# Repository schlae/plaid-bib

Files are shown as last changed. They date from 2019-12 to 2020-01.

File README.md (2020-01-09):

# The Plaid Bib - an Ad Lib MCA Clone

**This card uses the P82C611 bus interface chip and will not work with faster
MCA systems. For a more widely-compatible version, use the [Plaid Bib CPLD
version](https://github.com/schlae/plaid-bib-cpld).**

The Plaid Bib is a 100% compatible clone of the Ad Lib MCA sound card. This is
an Ad Lib card designed for Micro Channel Architecture machines, such as the
IBM PS/2 family and other compatibles from NCR, Tandy, Dell, and others.

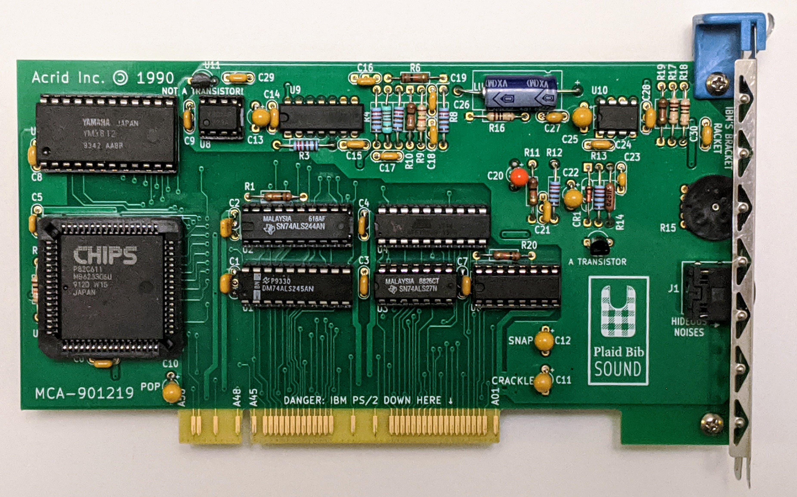
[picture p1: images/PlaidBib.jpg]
Plaid Bib photo


Here are the design files. The BOM includes Mouser Electronics part numbers for
everything except for the 82C611, YM3812, and YM3014B, all of which are
available from brokers in China such as UTSource.

[Schematic](https://github.com/schlae/plaid-bib/blob/master/PlaidBib.pdf)

[Bill of Materials](https://github.com/schlae/plaid-bib/blob/master/PlaidBib.csv)

[Fab Files](https://github.com/schlae/plaid-bib/blob/master/fab/PlaidBib-fab.zip)

Use caution when obtaining the P82C611 MCA bus interface part. There is another
chip with the same part number from OPTi, except it is a VLB IDE controller and
totally different.

## Fabrication Notes
This is a two-layer board, outer dimensions 6.452in x 3.475in (164mm x 88mm).
Thickness of the board is 0.063in (1.6mm). When ordering the board, specify
a card edge bevel of 20 degrees. The Dwgs.User layer includes a detail with
the dimensions of the bevel.

Ideally you should use selective gold plating for the edge fingers, but this
can get expensive for small orders. ENIG will work but the gold will rub off
pretty quickly.

For the soldermask color, pick whatever you want! The original was green.

## Assembly Notes
You may wish to socket U7, U8, and U4. These sockets are not included in the
BOM. U7 and U8 are the Yamaha synthesizer chips, and it is useful to be able
to swap them out in case you get a bad one. U4 is the PAL; consider using a
socket in case of programming difficulties.

## PAL Notes
There is a programmable logic device that implements the address decoder and an
address bit latch. The original card uses a 16L8, but the Plaid Bib uses a
readily-available Atmel ATF16V8B. Here is the
[WinCUPL source](https://github.com/schlae/plaid-bib/blob/master/pld/plaidbib.pld)
and the resulting 
[JEDEC file](https://github.com/schlae/plaid-bib/blob/master/pld/plaidbib.jed).
You will need a device programmer such as the low-cost TL866A/CS. 

## Bracket
MCA brackets are no longer available. You have a few options:
- Remove the bracket from an existing card, like a token ring card or something
- 3D print the bracket
- Use the card without a bracket at all

If you want to print your own, here are STEP models of the bracket and the
plastic clip.

[Bracket](https://github.com/schlae/plaid-bib/blob/master/mech/MCABracket.STEP)

[Clip](https://github.com/schlae/plaid-bib/blob/master/mech/MCAClip.STEP)

Please note that neither file is designed specifically for 3D printing; they're
meant to match the real hardware exactly. The clip might print just fine, but
the bracket is probably too thin to print well.

## Compatibility

Micro Channel machines operate at a variety of different bus speeds. Only the
slower ones are compatible with the Plaid Bib.

|PS/2 Model|Clock t(ns)|Default transfer(ns)|Extended transfer(ns)| Compatible?|
|-----|---|---|---|---|
| 50  | 100 | 300/1WS (I/O) | 300/1WS | Yes |
| 55  | 62.5 | 250/2WS | 375/4WS | Untested |
| 60  | 100 | 300/1WS (I/O) | 300/1WS | Yes/untested |
| 65  | 62.5 | 250/2WS | 375/4WS | Untested |
| 70  | 50 | 200/2WS | 300/4WS | No |
| 80  | 62.5, 50, 40 | 200 | 300 | No |
| 90  | 40 | 200 | 300 | No |
| 95  | 40, 30 | 200, 240 | 300, 320 | No |

The YM3812 FM synthesis chip has minimum timings that are somewhat too slow.
For example, the read pulse width minimum spec is 200ns. The 82C611 generates
the read pulse based on the MCA CMD signal, which asserts for only part of the
default transfer cycle. A fast machine like the model 90 has a default transfer
cycle time of 200ns, so CMD is low for only about 90ns. This is too short to
properly read from the FM chip, meaning that Ad Lib auto detect functions will
fail to see the card.

## Installation
You will need the ADF (adapter description file) in order to set up the Plaid
Bib on your MCA computer.

[Plaid Bib ADF](https://github.com/schlae/plaid-bib/blob/master/@70D7.ADF)

Place the file on a 3 1/2" floppy disk. After you install the card and boot
the computer, it will detect that a new card has been installed and prompt
you to insert the reference disk. Do this and follow the prompts. When the
setup utility asks you to insert the option disk, use the one that contains
the ADF file. After the setup utility configures the card, it will prompt
you to reboot the machine.

Once that's finished, try out the Plaid Bib with your favorite game!

## License
This work is licensed under a Creative Commons Attribution-ShareAlike 4.0
International License. See [https://creativecommons.org/licenses/by-sa/4.0/](https://creativecommons.org/licenses/by-sa/4.0/).

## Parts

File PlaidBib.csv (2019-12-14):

Item | Qty | Reference(s) | Value | Mouser
1 | 15 | C1, C2, C3, C4, C5, C6, C7, C8, C9, C14, C15, C24, C28, C29, C30 | 0.1uF | 581-AR215C104K4R
2 | 6 | C10, C11, C12, C13, C22, C25 | 10uF | 581-TAP106M025CRW
3 | 4 | C16, C17, C18, C19 | 4700pF | 581-AR211C472K4R
4 | 1 | C20 | 4.7uF | 581-TAP475K016SCS
5 | 1 | C21 | 1000pF | 581-AR211C102K4R
6 | 1 | C23 | 270pF | 594-S271K43SL0N6TK5R
7 | 1 | C26 | 220uF 16V | 647-TVX1C221MAD
8 | 1 | C27 | 0.047uF | 581-AR215C473K4R
9 | 1 | CR1 | 1N914 | 512-1N914
10 | 1 | J1 | Conn_01x03 | 490-SJ1-3553NG
11 | 1 | Q1 | 2N3904 | 512-2N3904BU
12 | 2 | R1, R20 | 1K | 291-1K-RC
13 | 6 | R3, R4, R7, R8, R12, R13 | 2.2K | 291-2.2K-RC
14 | 1 | R5 | 12K | 291-12K-RC
15 | 4 | R6, R10, R11, R19 | 10K | 291-10K-RC
16 | 1 | R9 | 1.5K | 291-1.5K-RC
17 | 1 | R14 | 8.2K | 291-8.2K-RC
18 | 1 | R15 | 10K | 688-RK14J11A000G
19 | 3 | R16, R17, R18 | 10 | 291-10-RC
20 | 1 | RN1 | 10K | 652-4606X-1LF-10K
21 | 1 | U1 | 74LS245 | 595-SN74LS245N
22 | 1 | U2 | 74LS244 | 595-SN74LS244N
23 | 1 | U3 | 74LS27 | 595-SN74LS27N
24 | 1 | U4 | PAL16L8 | 556-AF16V8B15PU
25 | 1 | U5 | P82C611
26 | 1 | U6 | 74LS109 | 595-SN74LS109AN
27 | 1 | U7 | YM3812
28 | 1 | U8 | YM3014B
29 | 1 | U9 | RC4136 | 595-RC4136N
30 | 1 | U10 | LM386N | 926-LM386N-4/NOPB
31 | 1 | U11 | L78L05_TO92 | 511-L78L05ACZ

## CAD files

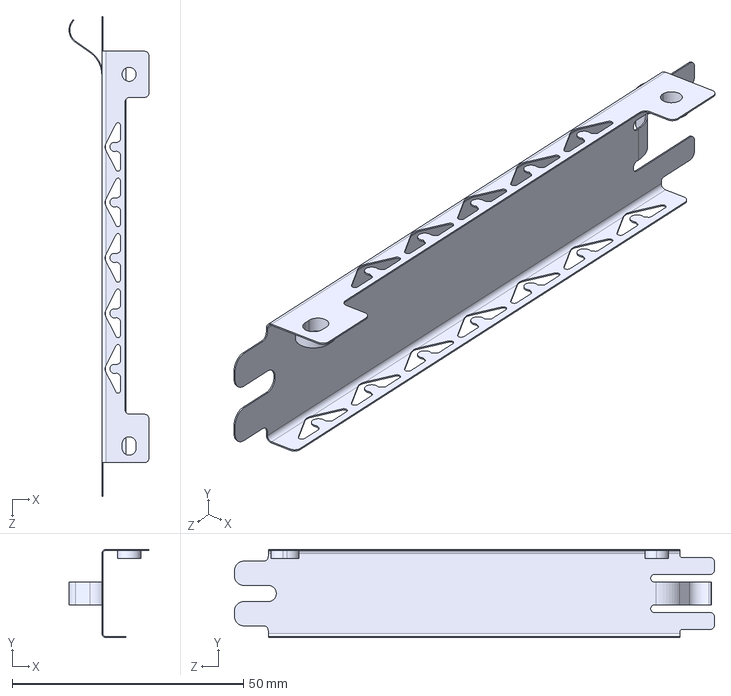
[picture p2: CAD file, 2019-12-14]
mech/MCABracket.STEP
17.3 x 19.1 x 103.8 mm

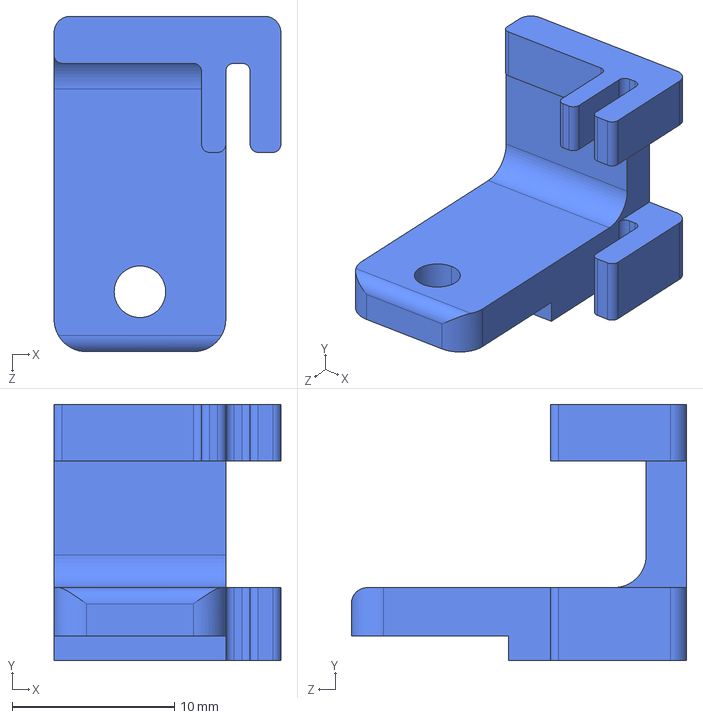
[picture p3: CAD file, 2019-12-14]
mech/MCAClip.STEP
14.0 x 15.8 x 20.7 mm

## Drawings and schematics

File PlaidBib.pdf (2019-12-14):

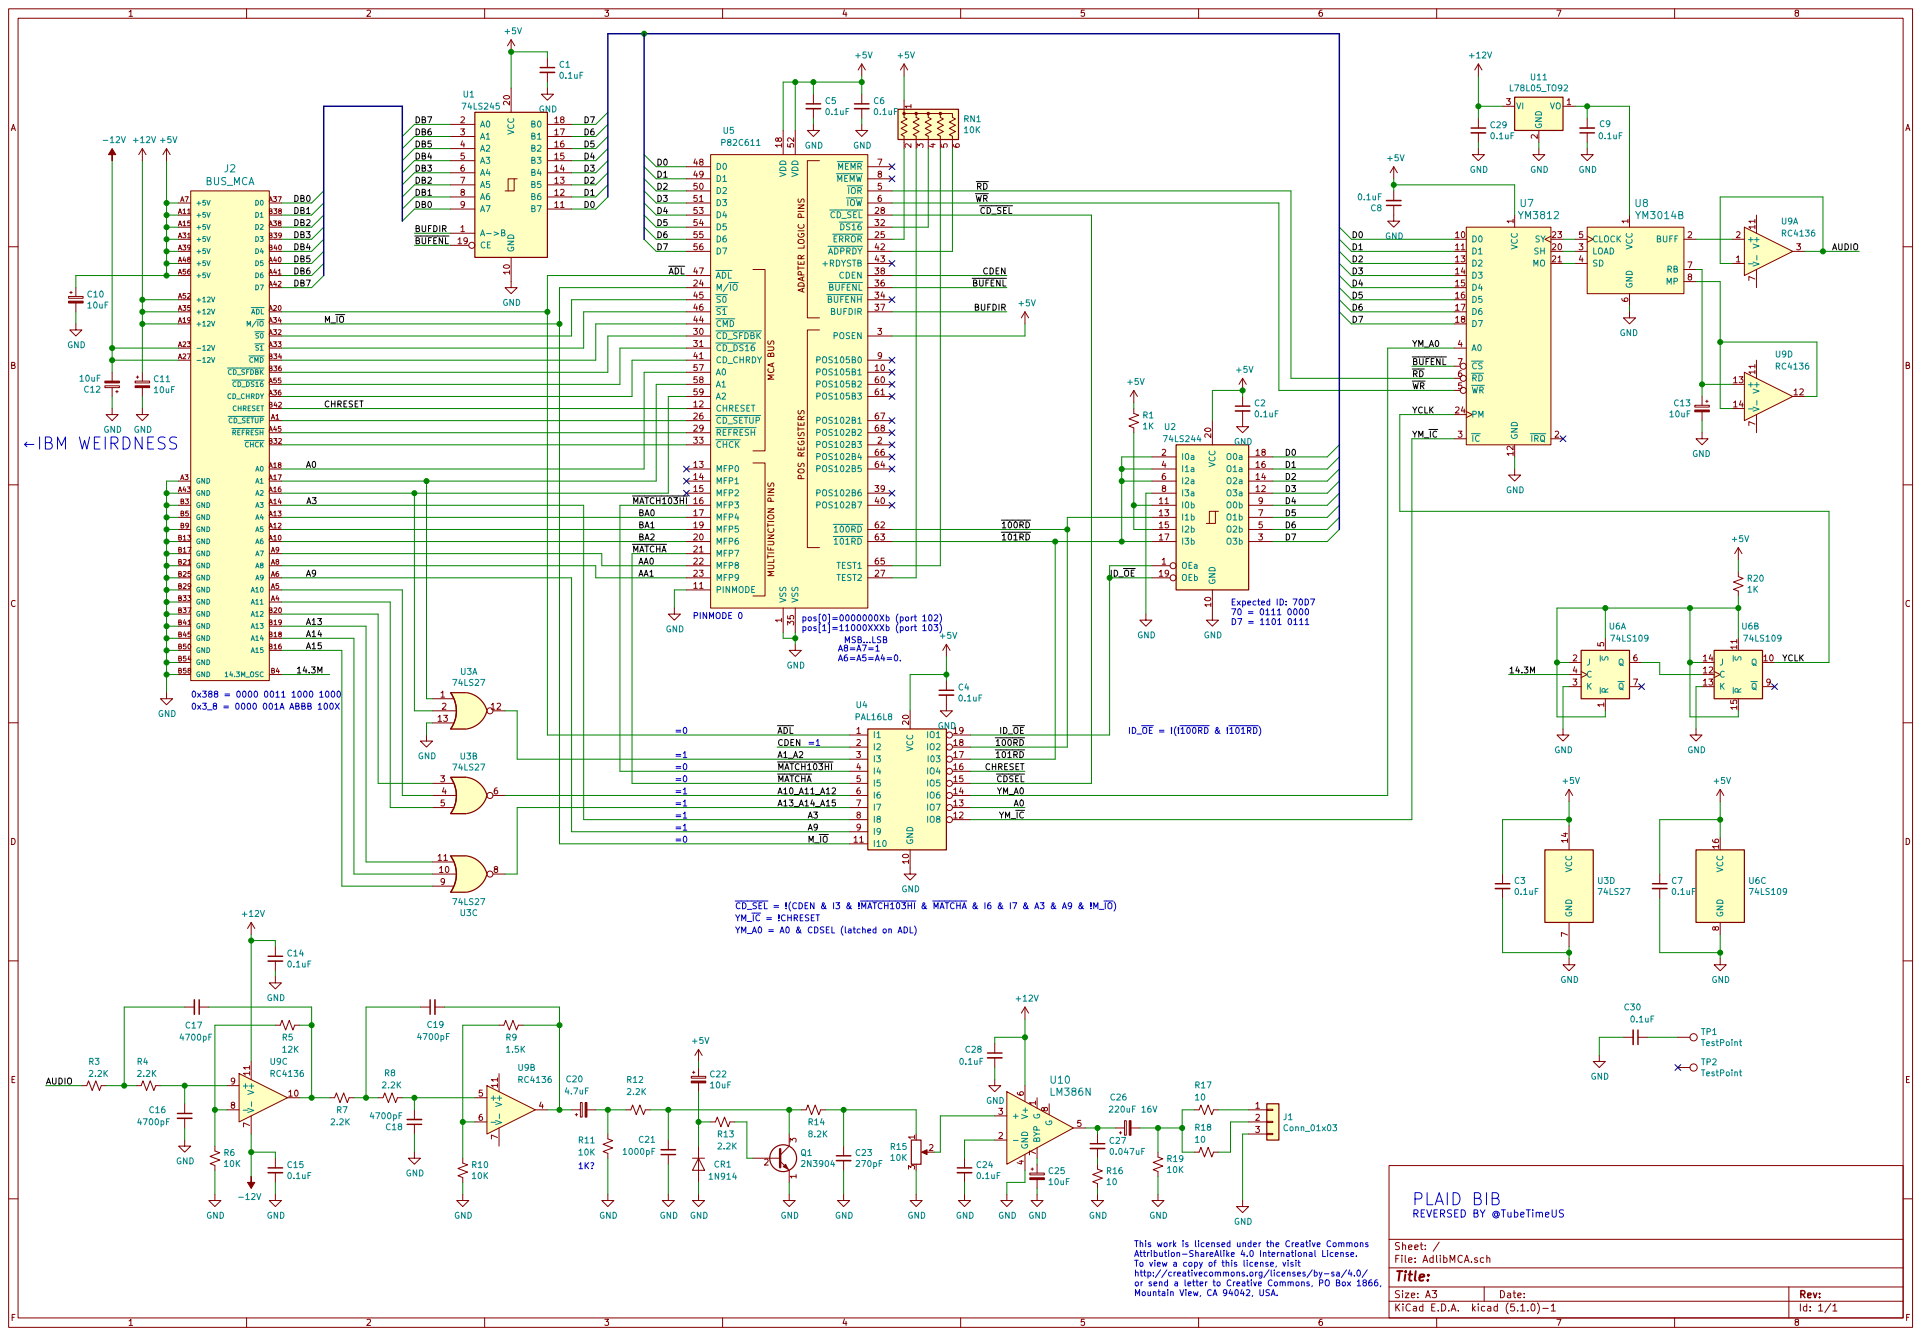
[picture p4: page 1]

1 POS105B1 10 PINMODE 11 CHRESET 12 MFP0 13 MFP1 14 MFP2 15 MFP3 16 MFP4 17 VDD 18 MFP5 19 POS102B3 2 MFP6 20 MFP7 21 MFP8 22 MFP9 23 M/IO 24 ERROR 25 CD_SETUP 26 TEST2 27 CD_SEL 28 REFRESH 29 POSEN 3 CD_SFDBK 30 CD_DS16 31 DS16 32 CHCK 33 BUFENH 34 VSS 35 BUFENL 36 BUFDIR 37 CDEN 38 POS102B6 39 POS102B7 40 CD_CHRDY 41 ADPRDY 42 +RDYSTB 43 CMD 44 S0 45 S1 46 ADL 47 D0 48 D1 49

pos[0]=0000000Xb (port 102)
pos[1]=11000XXXb (port 103) MSB...LSB

This work is licensed under the Creative Commons Attribution-ShareAlike 4.0 International License. To view a copy of this license, visit

Id: 1/1 Title: File: AdlibMCA.sch Sheet: /

http://creativecommons.org/licenses/by-sa/4.0/ or send a letter to Creative Commons, PO Box 1866, Mountain View, CA 94042, USA.

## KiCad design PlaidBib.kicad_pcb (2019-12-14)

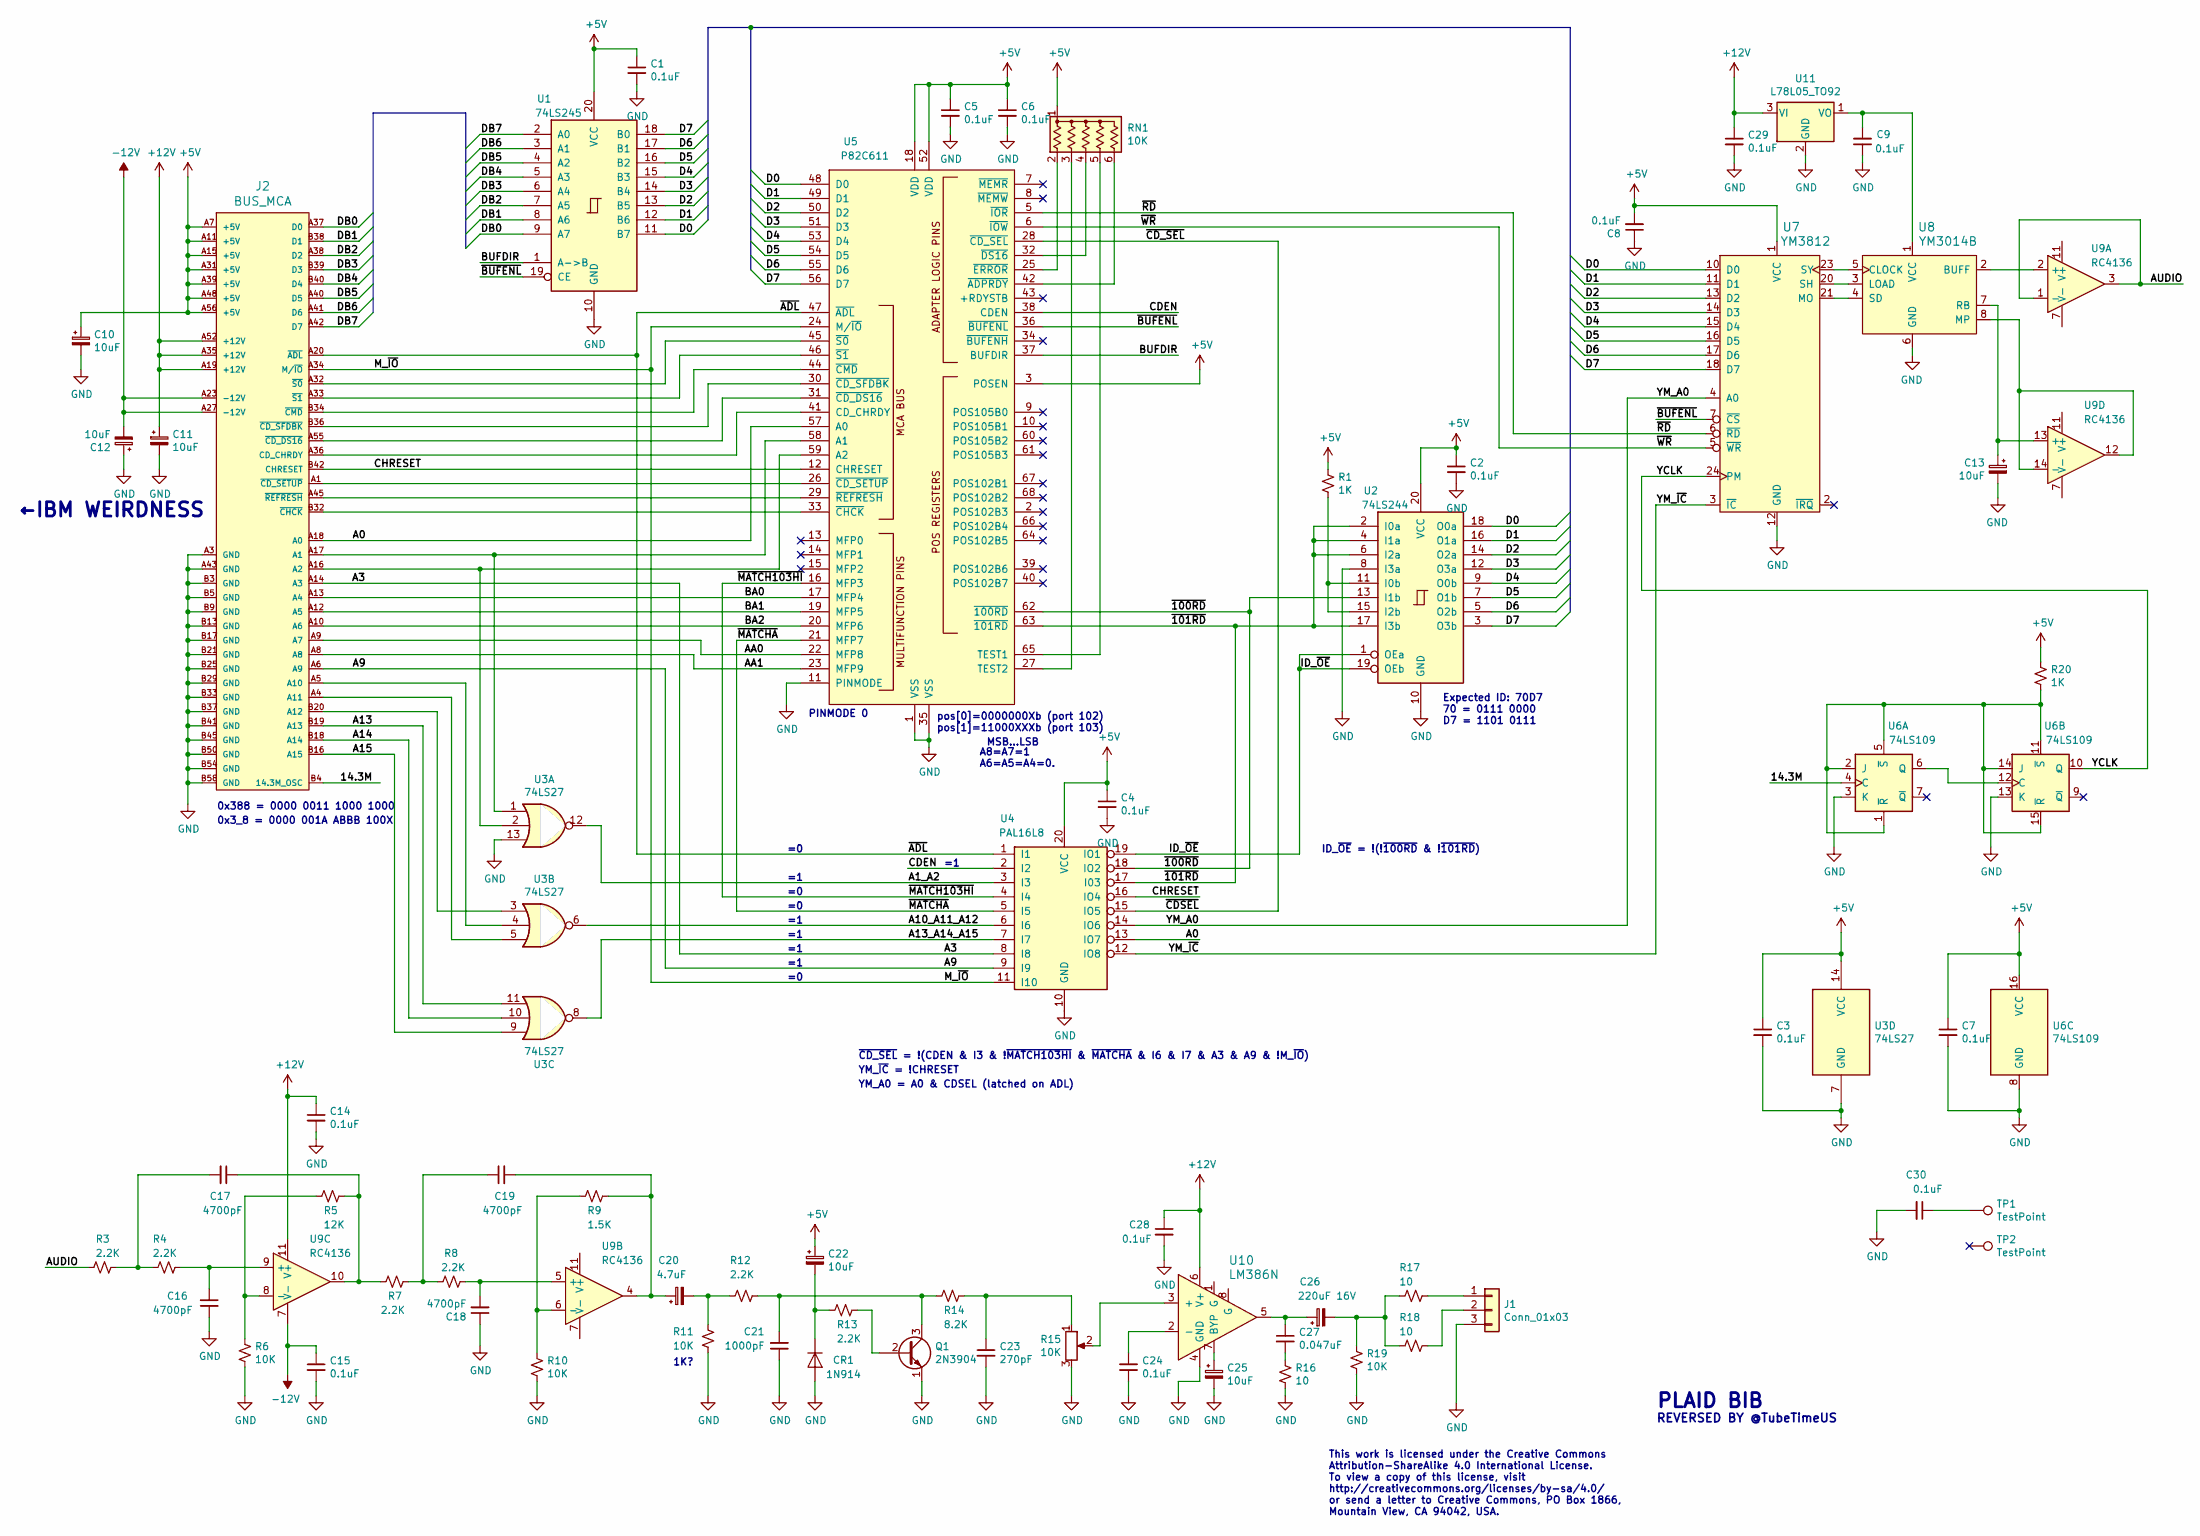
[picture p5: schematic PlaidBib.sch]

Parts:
C1, C2, C3, C4, C5, C6, C7, C8, C9, C14, C15, C24, C28, C29, C30: 0.1uF; CAP23; Mouser 581-AR215C104K4R
C10, C11, C12, C13, C22, C25: 10uF; CAPAP200; Mouser 581-TAP106M025CRW
C16, C17, C18, C19: 4700pF; CAP23; Mouser 581-AR211C472K4R
C20: 4.7uF; CAPAP200; Mouser 581-TAP475K016SCS
C21: 1000pF; CAP23; Mouser 581-AR211C102K4R
C23: 270pF; CAP23; Mouser 594-S271K43SL0N6TK5R
C26: 220uF 16V; CAPA1000; Mouser 647-TVX1C221MAD
C27: 0.047uF; CAP23; Mouser 581-AR215C473K4R
CR1: 1N914; DIOA500; Mouser 512-1N914
J1: Conn_01x03; SJ1-3553; Mouser 490-SJ1-3553NG
J2: BUS_MCA; BUS_MCA_ADLIB
Q1: 2N3904; TO92-IL; Mouser 512-2N3904BU
R1, R20: 1K; RESA500; Mouser 291-1K-RC
R3, R4, R7, R8, R12, R13: 2.2K; RESA500; Mouser 291-2.2K-RC
R5: 12K; RESA500; Mouser 291-12K-RC
R6, R10, R11, R19: 10K; RESA500; Mouser 291-10K-RC
R9: 1.5K; RESA500; Mouser 291-1.5K-RC
R14: 8.2K; RESA500; Mouser 291-8.2K-RC
R15: 10K; RK14J11A000G; Mouser 688-RK14J11A000G
R16, R17, R18: 10; RESA500; Mouser 291-10-RC
RN1: 10K; R_Array_SIP6; MPN 4606X-101-103LF; Mouser 652-4606X-1LF-10K
TP1, TP2: TestPoint; MH_125
U1: 74LS245; DIP300_20N; Mouser 595-SN74LS245N
U2: 74LS244; DIP300_20N; Mouser 595-SN74LS244N
U3: 74LS27; DIP300_14N; Mouser 595-SN74LS27N
U4: PAL16L8; DIP300_20N; Mouser 556-AF16V8B15PU
U5: P82C611; PLCC-68_THT-Socket
U6: 74LS109; DIP300_16N; Mouser 595-SN74LS109AN
U7: YM3812; DIP600_24N
U8: YM3014B; DIP300_8N
U9: RC4136; DIP300_14N; Mouser 595-RC4136N
U10: LM386N; DIP300_8N; Mouser 926-LM386N-4/NOPB
U11: L78L05_TO92; TO92-IL; Mouser 511-L78L05ACZ

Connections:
+5V: C1.1, C2.1, C3.1, C4.1, C5.1, C6.1, C7.1, C8.2, C10.1, C22.1, J2.A7 (+5V), J2.A11 (+5V), J2.A15 (+5V), J2.A31 (+5V), J2.A39 (+5V), J2.A48 (+5V), J2.A56 (+5V), R1.1, R20.1, RN1.1 (common), U1.20 (VCC), U2.20 (VCC), U3.14 (VCC), U4.20 (VCC), U5.3 (POSEN), U5.18 (VDD), U5.52 (VDD), U6.16 (VCC), U7.1 (VCC)
+12V: C11.1, C14.1, C28.1, C29.1, J2.A19 (+12V), J2.A35 (+12V), J2.A52 (+12V), U9.11 (V+), U10.6 (V+), U11.3 (VI)
-12V: C12.2, C15.1, J2.A23 (-12V), J2.A27 (-12V), U9.7 (V-)
/14.3M: J2.B4 (14.3M_OSC), U6.4 (C)
/A0: J2.A18 (A0), U4.13 (IO7), U5.57 (A0)
/A1_A2: U3.12, U4.3 (I3)
/A3: J2.A14 (A3), U4.8 (I8)
/A9: J2.A6 (A9), U4.9 (I9)
/A10_A11_A12: U3.6, U4.6 (I6)
/A13: J2.B19 (A13), U3.11
/A13_A14_A15: U3.8, U4.7 (I7)
/A14: J2.B18 (A14), U3.10
/A15: J2.B16 (A15), U3.9
/AA0: J2.A9 (A7), U5.22 (MFP8)
/AA1: J2.A8, U5.23 (MFP9)
/AUDIO: R3.2, U9.1 (-), U9.3
/BA0: J2.A13 (A4), U5.17 (MFP4)
/BA1: J2.A12 (A5), U5.19 (MFP5)
/BA2: J2.A10 (A6), U5.20 (MFP6)
/BUFDIR: U1.1 (A->B), U5.37 (BUFDIR)
/CDEN: U4.2 (I2), U5.38 (CDEN)
/CHRESET: J2.B42 (CHRESET), U4.16 (IO4), U5.12 (CHRESET)
/D0: U1.11 (B7), U2.18 (O0a), U5.48 (D0), U7.10 (D0)
/D1: U1.12 (B6), U2.16 (O1a), U5.49 (D1), U7.11 (D1)
/D2: U1.13 (B5), U2.14 (O2a), U5.50 (D2), U7.13 (D2)
/D3: U1.14 (B4), U2.12 (O3a), U5.51 (D3), U7.14 (D3)
/D4: U1.15 (B3), U2.9 (O0b), U5.53 (D4), U7.15 (D4)
/D5: U1.16 (B2), U2.7 (O1b), U5.54 (D5), U7.16 (D5)
/D6: U1.17 (B1), U2.5 (O2b), U5.55 (D6), U7.17 (D6)
/D7: U1.18 (B0), U2.3 (O3b), U5.56 (D7), U7.18 (D7)
/DB0: J2.A37 (D0), U1.9 (A7)
/DB1: J2.B38 (D1), U1.8 (A6)
/DB2: J2.A38 (D2), U1.7 (A5)
/DB3: J2.B39 (D3), U1.6 (A4)
/DB4: J2.B40 (D4), U1.5 (A3)
/DB5: J2.A40 (D5), U1.4 (A2)
/DB6: J2.A41 (D6), U1.3 (A1)
/DB7: J2.A42 (D7), U1.2 (A0)
/ID_~OE: U2.1 (OEa), U2.19 (OEb), U4.19 (IO1)
/M_~IO: J2.A34 (M/~IO), U4.11 (I10), U5.24 (M/~IO)
/YCLK: U6.10 (Q), U7.24 (PM)
/YM_A0: U4.14 (IO6), U7.4 (A0)
/YM_~IC: U4.12 (IO8), U7.3 (~IC)
/~100RD: U2.13 (I1b), U4.18 (IO2), U5.62 (~100RD)
/~101RD: U2.2 (I0a), U2.4 (I1a), U2.6 (I2a), U2.17 (I3b), U4.17 (I03), U5.63 (~101RD)
/~ADL: J2.A20 (~ADL), U4.1 (I1), U5.47 (~ADL)
/~BUFENL: U1.19 (CE), U5.36 (~BUFENL), U7.7 (~CS)
/~CDSEL: U4.15 (IO5), U5.28 (~CD_SEL)
/~MATCH103HI: U4.4 (I4), U5.16 (MFP3)
/~MATCHA: U4.5 (I5), U5.21 (MFP7)
/~RD: U5.5 (~IOR), U7.6 (~RD)
/~WR: U5.6 (~IOW), U7.5 (~WR)
GND: C1.2, C2.2, C3.2, C4.2, C5.2, C6.2, C7.2, C8.1, C9.1, C10.2, C11.2, C12.1, C13.2, C14.2, C15.2, C16.2, C18.1, C21.1, C23.2, C24.2, C25.2, C28.2, C29.2, C30.2, CR1.2 (A), J1.3, J2.A3 (GND), J2.A43 (GND), J2.B3 (GND), J2.B5 (GND), J2.B9 (GND), J2.B13 (GND), J2.B17 (GND), J2.B21 (GND), J2.B25 (GND), J2.B29 (GND), J2.B33 (GND), J2.B37 (GND), J2.B41 (GND), J2.B45 (GND), J2.B50 (GND), J2.B54 (GND), J2.B58 (GND), Q1.1 (E), R6.2, R10.2, R11.2, R15.3, R16.2, R19.2, U1.10 (GND), U2.8 (I3a), U2.10 (GND), U3.7 (GND), U3.13, U4.10 (GND), U5.1 (VSS), U5.11 (PINMODE), U5.35 (VSS), U6.3 (K), U6.8 (GND), U6.13 (K), U7.12 (GND), U8.6 (GND), U10.4 (GND), U11.2 (GND)
unnamed: C9.2, U8.1 (VCC), U11.1 (VO)
unnamed: C13.1, U8.7 (RB), U9.13 (+)
unnamed: C16.1, R4.1, U9.9 (+)
unnamed: C17.1, R5.1, R7.2, U9.10
unnamed: C17.2, R3.1, R4.2
unnamed: C18.2, R8.2, U9.5 (+)
unnamed: C19.1, R7.1, R8.1
unnamed: C19.2, C20.1, R9.1, U9.4
unnamed: C20.2, R11.1, R12.2
unnamed: C21.2, Q1.3 (C), R12.1, R14.2
unnamed: C22.2, CR1.1 (K), R13.2
unnamed: C23.1, R14.1, R15.1
unnamed: C24.1, U10.2 (-)
unnamed: C25.1, U10.7 (BYP)
unnamed: C26.1, C27.1, U10.5
unnamed: C26.2, R17.1, R18.1, R19.1
unnamed: C27.2, R16.1
unnamed: C30.1, TP1.1
unnamed: J1.1, R17.2
unnamed: J1.2, R18.2
unnamed: J2.A1 (~CD_SETUP), U5.26 (~CD_SETUP)
unnamed: J2.A4 (A11), U3.5
unnamed: J2.A5 (A10), U3.4
unnamed: J2.A16 (A2), U3.2, U5.59 (A2)
unnamed: J2.A17 (A1), U3.1, U5.58 (A1)
unnamed: J2.A32 (~S0), U5.45 (~S0)
unnamed: J2.A33 (~S1), U5.46 (~S1)
unnamed: J2.A36 (CD_CHRDY), U5.41 (CD_CHRDY)
unnamed: J2.A45 (~REFRESH), U5.29 (~REFRESH)
unnamed: J2.A55 (~CD_DS16), U5.31 (~CD_DS16)
unnamed: J2.B20 (A12), U3.3
unnamed: J2.B32 (~CHCK), U5.33 (~CHCK)
unnamed: J2.B34 (~CMD), U5.44 (~CMD)
unnamed: J2.B36 (~CD_SFDBK), U5.30 (~CD_SFDBK)
unnamed: Q1.2 (B), R13.1
unnamed: R1.2, U2.11 (I0b), U2.15 (I2b)
unnamed: R5.2, R6.1, U9.8 (-)
unnamed: R9.2, R10.1, U9.6 (-)
unnamed: R15.2, U10.3 (+)
unnamed: R20.2, U6.1 (~R), U6.2 (J), U6.5 (~S), U6.11 (~S), U6.14 (J), U6.15 (~R)
unnamed: RN1.2 (R1), U5.25 (~ERROR)
unnamed: RN1.3 (R2), U5.27 (TEST2)
unnamed: RN1.4 (R3), U5.32 (~DS16)
unnamed: RN1.5 (R4), U5.65 (TEST1)
unnamed: RN1.6 (R5), U5.42 (~ADPRDY)
unnamed: U6.6 (Q), U6.12 (C)
unnamed: U7.20 (SH), U8.3 (LOAD)
unnamed: U7.21 (MO), U8.4 (SD)
unnamed: U7.23 (SY), U8.5 (CLOCK)
unnamed: U8.2 (BUFF), U9.2 (+)
unnamed: U8.8 (MP), U9.12, U9.14 (-)

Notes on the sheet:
Expected ID: 70D7 70 = 0111 0000 D7 = 1101 0111
0x388 = 0000 0011 1000 1000
1K?
pos[0]=0000000Xb (port 102) pos[1]=11000XXXb (port 103)
MSB...LSB
A8=A7=1 A6=A5=A4=0.
PINMODE 0
←IBM WEIRDNESS
0x3_8 = 0000 001A ABBB 100X
ID_~OE~ = !(!~100RD~ & !~101RD~)
~CD_SEL~ = !(CDEN & I3 & !~MATCH103HI~ & ~MATCHA~ & I6 & I7 & A3 & A9 & !M_~IO~)
YM_~IC~ = !CHRESET
YM_A0 = A0 & CDSEL (latched on ADL)
PLAID BIB
REVERSED BY @TubeTimeUS
This work is licensed under the Creative Commons Attribution-ShareAlike 4.0 International License. To view a copy of this license, visit http://creativecommons.org/licenses/by-sa/4.0/ or send a letter to Creative Commons, PO Box 1866, Mountain View, CA 94042, USA.

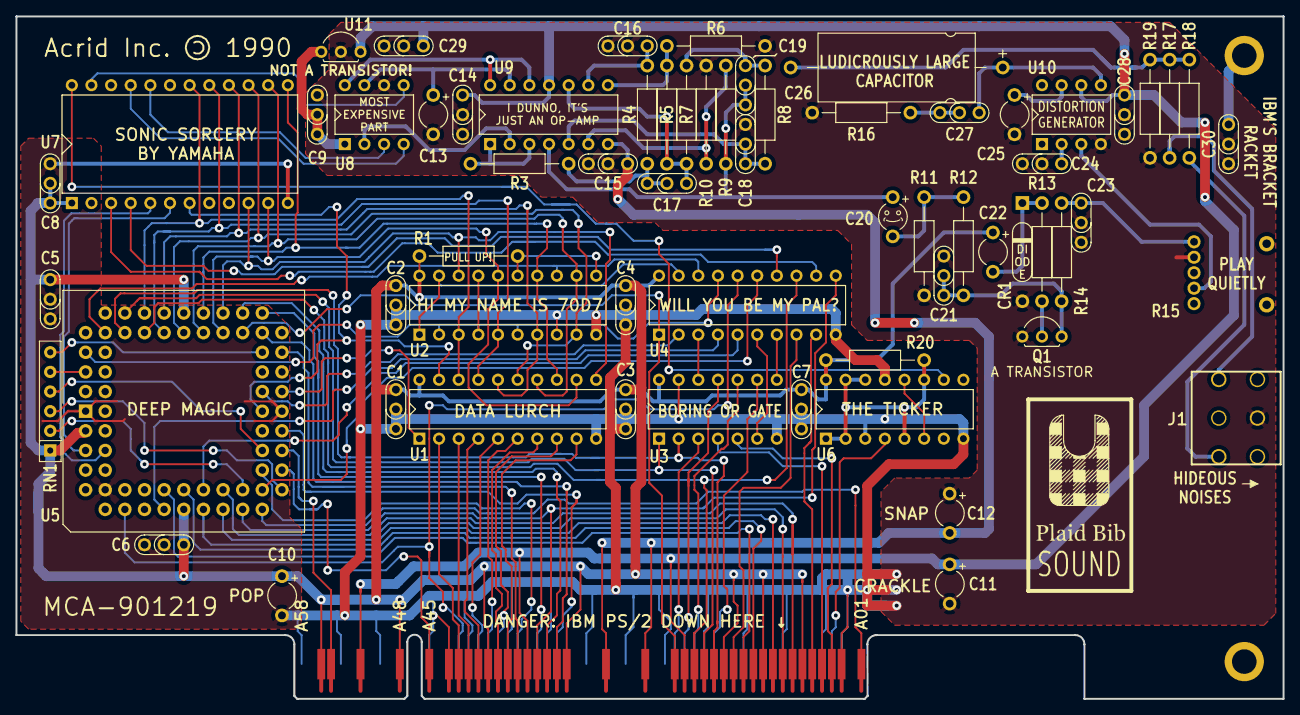
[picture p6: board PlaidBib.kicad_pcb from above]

Board: 2 copper layers, 163.9 x 88.3 mm, 67 parts (0 on the bottom side), 104 nets.

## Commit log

2019-12-14 initial Plaid Bib files
    [PlaidBib.csv, PlaidBib.kicad_pcb, PlaidBib.sch]
2019-12-14 add STEP files for bracket
    [MCABracket.STEP, MCAClip.STEP]

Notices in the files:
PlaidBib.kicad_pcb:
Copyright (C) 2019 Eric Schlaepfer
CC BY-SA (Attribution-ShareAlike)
